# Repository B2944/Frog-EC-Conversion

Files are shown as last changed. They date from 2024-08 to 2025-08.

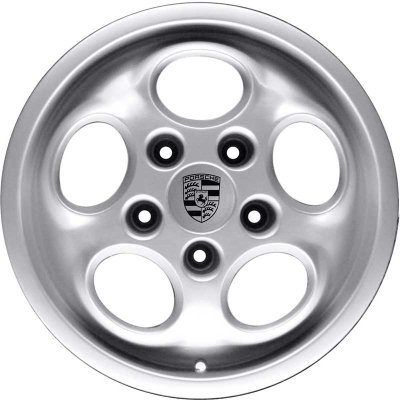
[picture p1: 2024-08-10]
Plate Files/24059-ml.jpg

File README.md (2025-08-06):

## Geonworks Frog TKL EC Conversion using the EC8X
Documentation of the Geonworks Frog TKL EC Conversion and EC8X PCB. This PCB can be found in stock on [ThoccExchange](https://thoccexchange.com) or purchased directly from me via Discord.

file (1)



### <ins>Build Specs:</ins> 
 
- Burgundy F13 WKL Frog TKL
- EC8X PCB
- Topre converted Alu 5202 1.2mm plate
- YMDK Housings
- KLC Playground MX Sliders
- YMDK 2U Assemblies and 7U Assembly (Lubed with Krytox 206g2)
- 0.5mm ThockRings
- Metakeebs 45g Domes 
- Novatouch Springs

- DCX WoB

## Build Guide
1. Thread the standoffs into the plate using the smaller screws out of the two packs. (Not needed if your plate is from the threaded batch) 
2. Put the spacebar housing into the plate with the bar facing upwards towards the f row. 
3. Click the 1U housings into the plate except for the ones that are positioned above the space bar stabiliser. 
4. Cut the 1U housings that will fill this area like so:



6. Push the sliders into the housings. 
7. Place the domes into the housings. 
8. Place the conical springs in the domes (make sure non are stacked as this causes issues). (You can gently drop the springs that are stacked onto your desk to get them separate easier)
9. Place the pcb onto the back of the plate.
10. Screw the pcb and plate together using the bigger screws out of the two packs. (or using the M2.5x8mm if your plate is from the threaded batch). 
11. Put the tadpoles into the plate, preferably the 90A tadpoles to reduce the chances of bottoming out. 

## Parts required for the conversion
- Domes, EC Springs, Sliders (Topre Stem or MX), Housings, EC8X PCB, Supported Plate, M2.5 8mm Waferhead Screws // M1.6x3, M1.6x4 + M1.6 Standoffs. 

  - Domes, EC Springs, MX Sliders and housings can be sourced aftermarket from online vendors such as [Deskeys](https://deskeys.io), [KLC Playground](https://klc-playground.com/products/instock-ec-kits-and-packs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) and 
  [ThoccExchange](thoccexchange.com)

  - Topre stem sliders currently have no aftermarket option so will need to be harvested from a board or bought from someone who has already harvested them, these can be found in trade channels found on enthusiast discords. If you fail to find them you can simply buy a 
  realforce to harvest yourself (preferably broken as to not ruin perfectly good boards). This is also a bonus as it will give you the domes, housing, EC springs and keycaps often at a lower price than the aftermarket options.

> [!NOTE]
> You may upset a few people when harvesting perfectly good boards, so please do try and look for a Junkforce. :smile_cat:

## Getting your own plates manufactured

> [!NOTE]
> Ordering your own plates can be rather expensive per unit when doing a small order, so I will be hosting a group order soon after these PCBs launch.



However, if you are sure you want to get your own made then simply download the plate file for your desired layout from the [plate files](https://github.com/B2944/Frog-EC-Conversion/tree/main/Plate%20Files) folder along with the drawing diagram (beware that there are two options, one which uses standard topre stabilisers and one that uses MX stabilisers for the spacebar to avoid the clearance issues found when using the topre stabiliser). When going down this route you have a few options:

### 1. Get a plate laser cut

This method requires you to tap your own holes with an M2.5 Thread Tap. You will also have to adjust the plate files screw hole diameter to around 2mm to leave material for the tapping process. 

### 2. Get a plate manufactured with threaded holes

This method will increase manufacturing costs but will ensure that the plate is properly threaded to avoid hiccups in the build process. Make sure to supply your manufacturer with the drawing diagram to ensure they understand the thread specs. 

mounting-screws

### 3. Laser cut plate with threaded spacers

   spacer

This method makes use of a threaded standoff to secure the plate and pcb together using 2 screws, one from above the plate and one below the pcb, the benefit of this is that you can use softer plates like POM or PC which can not be easily threaded. A 4mm standoff is required in order to fit them in between the switch housing without clearance issues. This method makes use of more hardware, but also reduces plate manu costs as you now only require a simple laser cut plate. (Change info to M1.6 screws and standoffs once I test. **This will require plate holes to be adjusted for smaller screws as M2.5 screws have clearance issues inbetween the housings. 

For this method you will need:
   - M1.6 Threaded Standoff spacers
   - M1.6 Waferhead Screws 3mm and 4mm (3mm through plate, 4mm through pcb)

### 4. Laser cut plate with screws and nuts

Get a plate laser cut then place 10mm M2 Waferhead screws through the top of the plate through to the PCB, then tighten some low profile M2 nuts on the back of the PCB.
  - This method is ideal as aluminium threads can be weak so it avoids the risk of stripping an expensive plate. 
  - This method is also much cheaper than a threaded plate and easier than any of the standoff options. 

### <ins>Screw Types</ins>

When choosing a screw for an EC conversion, you must take into account the amount of clearance underneath the PCB in the case. For this conversion of the Frog, there is not much room so we must opt for the waferhead/flad head style of screw to maximise clearance to avoid the pcb touching the base of the case. 



## Layout Support

Layout Support for PCB

## VIA

- Whilst waiting for the Firmware to be pushed to the main branch of VIA so the PCB is automatically recognised, you can use this [VIA](https://app-6w4.pages.dev) link. You could also enable the design tab in via settings and upload this [JSON](https://github.com/user-attachments/files/19264844/8X.EC-A0-875.json).
- If you find yourself having issues with the firmware, please message me on Discord or open an issue on here.

## Tasks left to complete 
- [X] Supporting plates for all Frog TKL Layouts (F12 and F13) 
- [ ] Implement o-ring cutouts for next batch to allow support of all H87/H88 TKLs.
- [ ] Integrated o-ring Plates
- [ ] Frog TKL Integrated Plates
- [x] Host groupbuy for Frog TKL Plates. 

# PCB Design and Compatibility

- I was heavily inspired after discovering Decoys reddit post on their F12 Frog TKL conversion, however once I contacted them to gain a better understanding of the conversion I realised that there was no readily available EC PCB that supported F13 layouts. This lead to the commissioning of the EC8X and the adjusting of the MX Plate file to convert it to accomodate topre housings by using CIPs plate generator to calculate the spacings. 
  
Each round of PCBs will be inspired by a different vehicle. Once this batch is sold through I will post an interest check to gauge an idea of how many to order for round 2. 

1. <code>Porsche 944</code>
   - Limited to 16 units. 15 USB C and 1 JST Variant. This round features a '944' lettering silkscreen above the nav cluster and a complimentary silkscreen on the back of the PCB of the NA 2.5L inline 4 found in the Porsche 944 and 944 S throughout production during 
   1982-1989. The plates were also designed with this in mind, leaving a cutout above the arrow cluster to view the '944' silkscreen. 

- The PCB is 1.6mm and fully configurable in VIA.
- Screw hole diameter: 2.8mm

### <ins>Compatibility</ins>

- This PCB should work with most TKLs, which do not require O-ring cutouts on the PCB for mounting and also use top mount USB C on the PCB, however I hope to put out a more thorough compatibility list soon. Compatibility for o-ring mount TKLs is in development in the form of an integrated o-ring plate. In addition, I will also be releasing a non o-ring integrated plate for the Frog TKL to maintain that HHKB Plate feeling. 

> [!CAUTION]
> **This PCB will not work with TKLs which require o-ring cutouts**

## Sound Test
https://github.com/user-attachments/assets/a239d422-3148-4d07-928c-a3f391c110ee

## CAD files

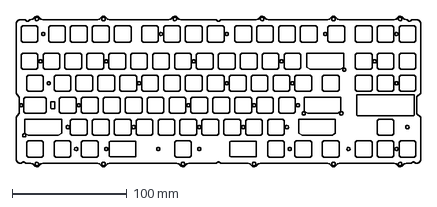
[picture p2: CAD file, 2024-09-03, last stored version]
Plate Files/F13 Plates/Topre Stabs/ANSI/F13 ANSI Full Right Shift Plate.dxf
352.0 x 131.0 mm

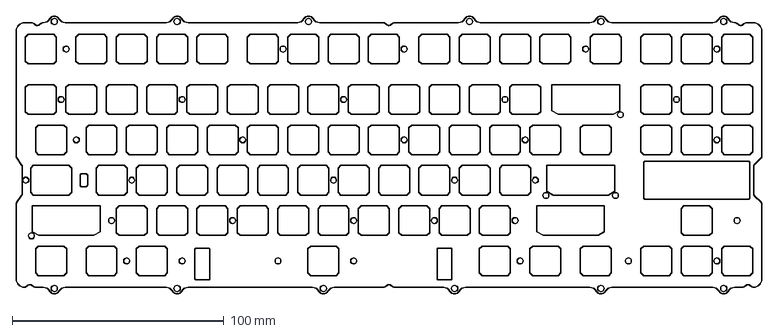
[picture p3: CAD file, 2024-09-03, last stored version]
Plate Files/F13/MX Stabs/ANSI/F13 ANSI Full Right Shift Plate/F13 ANSI Full Right Shift Plate MX Stabs.dxf
352.0 x 131.0 mm

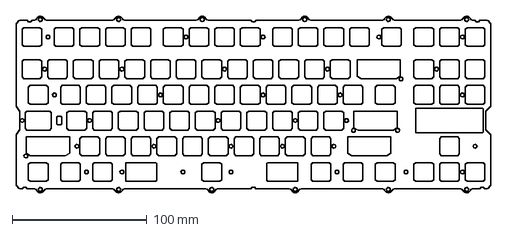
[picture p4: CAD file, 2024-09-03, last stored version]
Plate Files/F13/Topre Stabs/ANSI/F13 ANSI Full Right Shift Plate/#F13 ANSI Full Right Shift Plate.dxf
352.0 x 131.0 mm

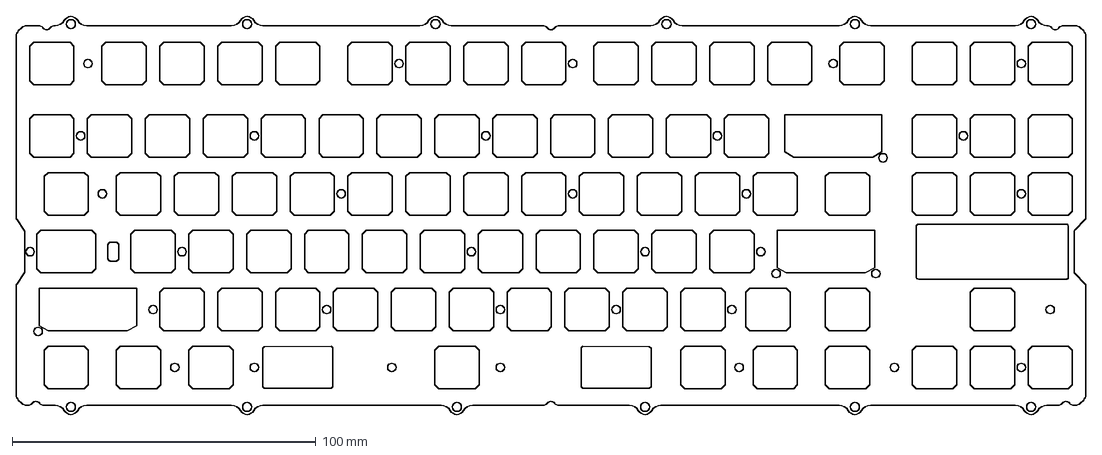
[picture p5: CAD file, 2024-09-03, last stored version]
Plate Files/F13/Topre Stabs/ANSI/F13 ANSI SPLIT RIGHT SHIFT/F13 ANSI SPLIT RIGHT SHIFT.dxf
352.0 x 131.0 mm

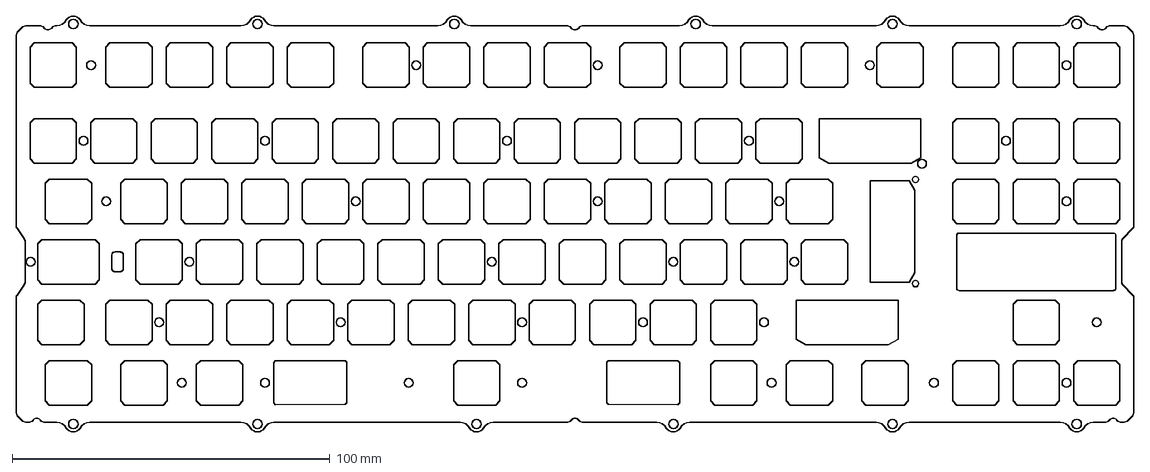
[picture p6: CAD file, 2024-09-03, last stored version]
Plate Files/F13/Topre Stabs/ISO/ISO Small Left Shift Plate/F13 ISO, Smallshift.dxf
352.0 x 131.0 mm
